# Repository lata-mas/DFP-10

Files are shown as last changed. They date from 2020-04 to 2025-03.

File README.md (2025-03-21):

# Dispositivo Factor de potencia

Este dispositivo se realizó gracias al apoyo del proyecto UNAM-PAPIIT IT103023.

El dispositivo FP-10 es un monitor de energía electrica desarrollado para medir parametros que permitan llevar un seguimiento del consumo energetico de un lugar, puesto que los datos obtenidos son enviados a una plataforma de internet para su visualizacion del tiempo de medición transcurrido. El dispositivo mide las siguientes variables: voltaje, corriente y factor de potencia. El monitor esta diseñado  para ser usado en una instalación trifásica y capaz de medir hasta 10 lineas.

A continuación se muestra el esquema general del dispositivo y una descripcción breve de los parametros que mide:

1. Corriente
2. Voltaje
3. Factor de potencia

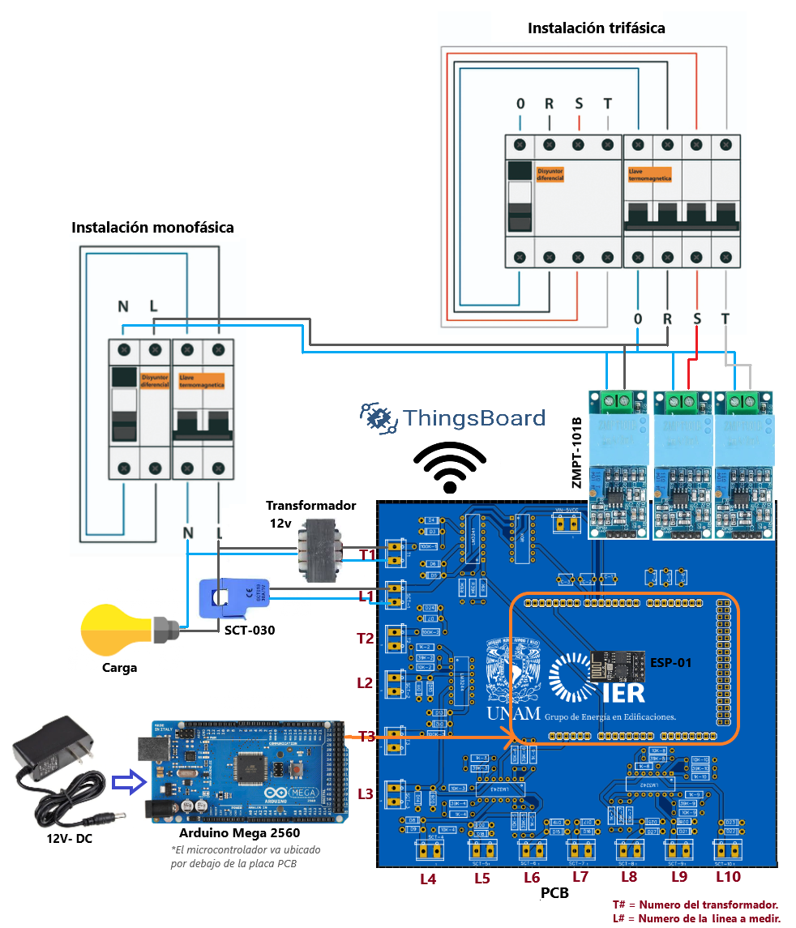
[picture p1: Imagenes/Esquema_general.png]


[Diagrama electrico](https://github.com/Dispositivos-Edificio-Bioclimatico/DFP-10/blob/master/Diagramas/circuito_acondicionamiento.png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)

**Corriente**

Sensor propuesto: SCT-013-030

El SCT-013-030 es un sensor de corriente no invasivo que permite medir la intensidad que atraviesa un conductor sin necesidad de cortar o modificar el conductor. La medición se realiza por inducción electromagnética y puede soportar hasta 30A.

**Voltaje**

Sensor propuesto: ZMPT101B

Es un módulo utilizado para medir la tensión de fase de corriente alterna. El sensor de voltaje AC está diseñado a partir de un transformador, por lo cual única y exclusivamente se puede utilizar para medir el voltaje de Corriente Alterna. El sensor incluye un circuito de amplificador operacional de precisión, señal para muestreo adecuado y función de compensación.
Puede medir hasta 250 V de AC de acuerdo con la salida analógica, la cual es ajustable.

**Factor de potencia**

Para medir el factor de potencia con un microcontrolador, se utilizan amplificadores operacionales para detectar el paso por cero de las señales de voltaje y corriente y para determinar el cambio de fase entre la fase de corriente y el voltaje. La medida del desfase se realiza únicamente para la fundamental entre corriente y tensión. Los amplificadores operacionales convierten señales de ondas sinusoidales con diferentes amplitudes provenientes de equipos de medición (pueden ser resistivos, divisores resistivos o transformadores de corriente y transformadores de tensión) en ondas rectangulares con una amplitud de aproximadamente 4 V, que luego se conectan a las entradas de la puerta XOR TTL. 

La salida de la puerta lógica XOR será 1 solo cuando las entradas tengan señales diferentes para cargas reactivas y la salida de la puerta lógica XOR será 0 cuando la carga sea resistiva. Entonces, cuando las fases de voltaje y corriente comienzan y terminan al mismo tiempo, la salida de la puerta lógica XOR será 0, y cuando la carga es inductiva o capacitiva, la salida de la puerta lógica XOR es 1, porque hay una diferencia de fase entre el voltaje y la corriente.

[Diagrama electrico](https://github.com/Dispositivos-Edificio-Bioclimatico/DFP-10/blob/master/Diagramas/Circuito%20factor%20de%20potencia.png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)

La lista de la electronica y materiales del dispositivo se encuentra en el archivo  [materiales](https://github.com/Dispositivos-Edificio-Bioclimatico/DFP-10/blob/master/Materiales/Lista_materiales_fp10.xlsx) o en [lista_drive](https://docs.google.com/spreadsheets/d/1BcxM7iUYsvm2OvhtAZ04L2_tH826wTiQOnGWFX_L0z4/edit)

## Elementos del repositorio
- [ ] Lista de costos
- [ ] src/ completos
- [ ] Pictograma de conexión
- [ ] Esquemático de conexión
- [ ] Archivos de diseño PCB
- [ ] Archivos gerber para el maquinado del PCB
- [x] Lista de materiales
- [ ] Planos CAD
- [ ] Archivos de diseño CAD
- [ ] Archivos STL para impresión 3D
- [ ] Manual de operación
- [ ] Manual de ensamble
- [ ] Fichas técnicas o datasheet de los módulos, sensores y componentes usados
- [ ] Documento de errores, soluciones y recomendaciones

### 1.1 Sobre los autores

|Nombre|Instituto/Organización|Email|
| --- | --- | --- |
|Juan Valle Bahena|ITZ|juanvb999@gmail.com|
|Guillermo Barrios del Valle|IER-UNAM|gbv@ier.unam.mx|
|Guillermo Ramírez Zúñiga|IER-UNAM|guraz@ier.unam.mx|
|Giovanni Velazquez Avilez ||velazquezgio96@gmail.com|

------------

# 2. Alcance

El dispositivo Factor de potencia tiene como alcance, en esta etapa, contar con toda la documentación necesaria  e incluso en atapa inicial de pruebas, después de ser trabajado por un grupo de personas se espera que el proyecto tenga todo lo que se necesita para que otras personas puedan entender el funcionamiento y requisitos de operación.

La audiencia a la que está destinada es:

- Por el momento a personal del IER-UNAM que se encuentra trabajando en el proyecto "Edificios demostrativos de diseño bioclimático en clima cálido subhúmedo en el Instituto de Energías Renovables UNAM".

Proyecto número 291600 del Fondo de Sustentabilidad Energética.
- Compañeros que se interesen en aportar al proyecto para mejorar o para replicarlo directamente.

------------

### Thingsboard

Dispositivo:
[**JUAN_VALLE_ENERGÍA**](http://iot.ier.unam.mx:8080/devices)

Dashboard:
[**JUAN_VALLE_ENERGÍA**](http://iot.ier.unam.mx:8080/dashboards/a7021b60-13df-11eb-9c3f-d1ead9980bc3)

**Las credenciales para acceder a Thinsgboard deberán ser solicitadas a los doctores**
------------

## PENDIENTES
1.- Comprar el sensor de corriente Hall Split core HSTS016L y hacer pruebas para verificar que el Factor de Potencia (FP) sea correcto.

2.- Poner una carcasa al dispositivo como proteccion para el sistema.

3.- Instalar el dispositivo en un edificio para probar la medición de las 10 lineas.

## RECOMENDACIONES
1.- Si se replica el sistema:

      * Montar el circuito en una placa de pruebas antes de montar en PCB para verificar que todos los componentes esten bien.
      
      * Será de ayuda usar un osciloscopio, para verificar que los circuitos integrados LM324N Y CD4030BE esten procesando la señal correctamente.
2.- Si el modulo ESP-01 (wifi) no logra inicializar se resuelve cambiando la velocidad de comunicación serial del modulo, en soft.begin (9600 o 115200).
      
3.- **IMPORTANTE** - **Extremar precauciones a la hora de hacer pruebas, ya que se trabaja con un voltaje que puede poner en riesgo la vida.**

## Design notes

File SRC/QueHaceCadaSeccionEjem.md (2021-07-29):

# Dispositivo Factor de potencia
Repositorio para el proyecto de medición del factor de potencia eléctrica para el nuevo edificio del IER-UNAM.

Esta versión del proyecto se conforma de un código modular para facilitar la manipulación de ciertos parámetros que nos ayuden a monitorear el consumo de energía eléctrica en los diferentes circuitos eléctricos del edificio nuevo del IER-UNAM.

A continuación se explican cada una de las funciones definidas en el archivo "funciones.py"

**Clase conteo**

Esta clase crea un objeto, este objeto será el sensor que se utilizará para la medición del flujo de agua.

La clase se compone de seis métodos. 

**Método init**

El método **init** no es más que para definir la varibale contador y la variable de entrada pin.

**Método callback**

El método **callback** es el que sirve para aumentar en 1 la variable contador cada señal recibida.

**Método irq**

El método **irq** es el que detecta cada pulso digital y envía la señal al metodo callback.

**Método ecuaciones**

Este método es el que aplica las constantes de conversión al conteo de pulsos digitales para así obtener una variable en Litros.

**Método datos**

Este método tan solo sirve para empaquetar los datos junto con una etiqueta para que estén listos.
para ser publicados en Thingsboard.	

**Método publica**

Este metodo se encarga de verificar si hay algún consumo de agua, de serlo así almacena los datos, en cuanto detecta que ya no lo hay, comineza un conteo, el conteo se interrumpe si vuelve a haber consumo, si el conteo concluye, publica los datos en Thingsboard.

**Última actualización de códigos por Miguel Ángel**

A continuación se explica de forma breve como se compone el código.

El código se modificó para hacer lecturas de ocho sensores. Cuenta con ocho secciones, una para cada número de sensores que se ocuparán. Todas las secciones se encuentran bloqueadas (comentadas). Esto con el fin de que se descomente la sección que se requiera, la primera sección es para un sensor, la segunda es para dos sensores y así sucesivamente hasta llegar a los ocho sensores.

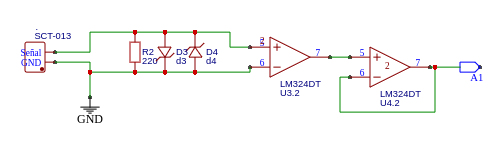
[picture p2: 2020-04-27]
Diagramas/circuito corriente.png

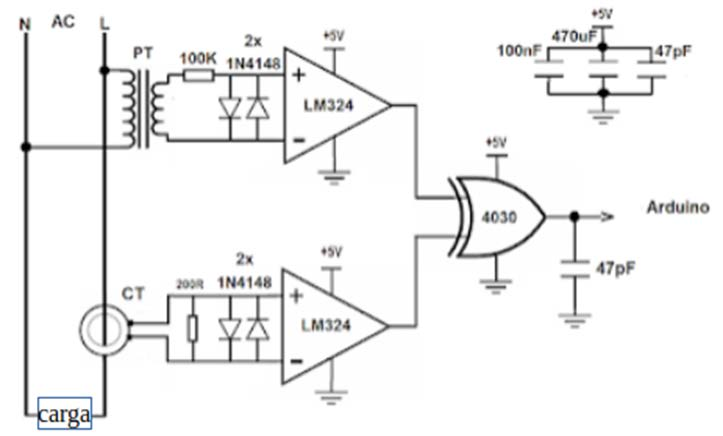
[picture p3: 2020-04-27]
Diagramas/Circuito factor de potencia.png

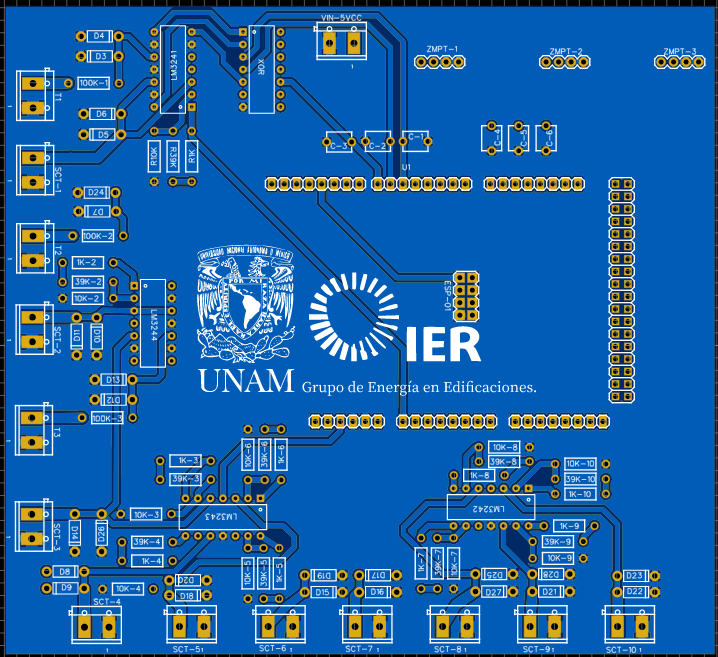
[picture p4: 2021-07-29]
Diagramas/pcb_10_fases_easyeda.png

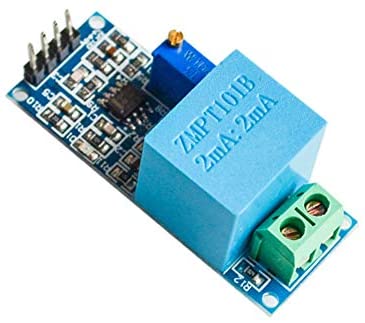
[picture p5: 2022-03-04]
Imagenes/zmpt101b.jpg

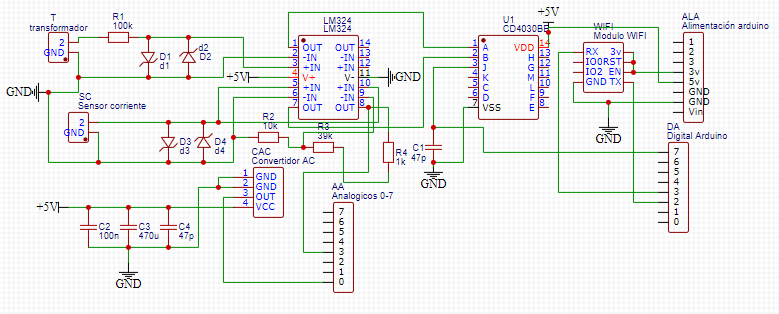
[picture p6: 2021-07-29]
Diagramas/circuito_acondicionamiento.png

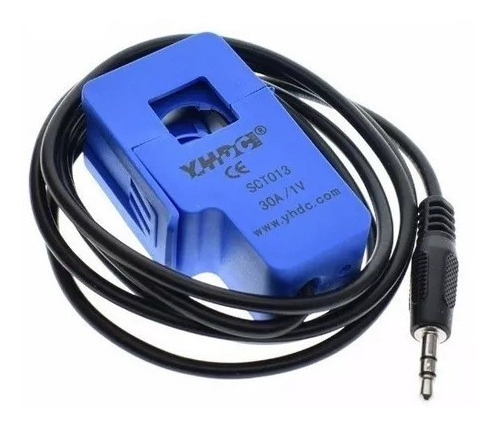
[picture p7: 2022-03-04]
Imagenes/sct_013_030.jpg

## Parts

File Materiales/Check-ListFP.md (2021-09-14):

- [x] Lista de costos
- [x] SRC completos
- [x] Pictograma de conexión
- [x] Esquemático de conexión
- [x] Archivos de diseño PCB
- [x] Archivos gerber para el maquinado del PCB
- [x] Lista de materiales
- [x] Planos CAD
- [x] Archivos de diseño CAD
- [x] Archivos STL para impresión 3D
- [ ] Manual de operación
- [ ] Manual de ensamble
- [x] Fichas técnicas o datasheet de los módulos, sensores y componentes usados
- [ ] Documento de errores, soluciones y recomendaciones

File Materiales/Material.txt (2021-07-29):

Lista de material para armar un pcb completo:
10 sensores sct013 de 30A-1v
3 sensores zmpt101b
3 transformadores de 110v a 12v
1 compuerta logica xor (con su base o zocalo)
4 CI Lm324 (con sus bases zif o zocalos en caso de ser necesarios)
14 bloques de 2 terminales (borneras verdes)
2 tiras de pines macho para ensamblar el arduino mega al pcb.
3 resistencias 100k
10 resistencias de 1k
10 resistencias de 39k
10 resistencias de 10k
26 diodos zener de 5v
capacitores : 4 de 47pf, 1 de 100 nf, 1 de 470uf
1 arduino mega.
1 modulo esp01 (wifi)

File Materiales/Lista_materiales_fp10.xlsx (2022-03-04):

Lista de Materiales
Cantidad | Componente | Link de compra
10 | SCT-030 | https://www.agelectronica.com/detalle.php?p=OKY3318-2
3 | ZMPT101B | https://articulo.mercadolibre.com.mx/MLM-696910645-sensor-de-voltaje-ac-zmpt101b-transformador-de-tension-_JM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
3 | Transformador 12V | https://www.agelectronica.com/detalle.php?p=TRANS-12/1200
4 | LM324 | https://www.agelectronica.com/detalle.php?p=LM%20324N
1 | XOR (CD4030BE) | https://www.agelectronica.com/detalle.php?p=CD%204030BE
26 | Diodo Zener | https://www.agelectronica.com/detalle.php?p=1N%204728A
3 | R100K | https://www.agelectronica.com/detalle.php?p=RC-100K/1/2
10 | R1K | https://www.agelectronica.com/detalle.php?p=RC-1K/1/2
10 | R39K | https://www.agelectronica.com/detalle.php?p=RC-39K/1/2
10 | R10K | https://www.agelectronica.com/detalle.php?p=RC-10K/1/2
4 | C47pF | https://www.agelectronica.com/detalle.php?p=CC-47/1000V-WELSON
3 | C470uF | https://www.agelectronica.com/detalle.php?p=CE-470/35V-TEAPO
3 | 100 nF | https://www.agelectronica.com/detalle.php?p=104M06QC150*
1 | ESP-01 | https://www.agelectronica.com/detalle.php?p=ESP-01S
1 | Arduino Mega 2560 | https://www.agelectronica.com/detalle.php?p=A000067
1 | Eliminador 12v | https://www.agelectronica.com/detalle.php?p=GFP181U-1210/JH
14 | Bornera 2 pines | https://www.agelectronica.com/detalle.php?p=GFP181U-1210/JH

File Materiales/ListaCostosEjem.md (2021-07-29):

# Lista de costos del Dispositivo Factor de Potencia Eléctrica
#### Título del diseño:|Dispositivo Factor de Potencia Eléctrica|
#### Fecha de diseño:|Martes 28/Julio/2021 | 
#### Última modificación del diseño:|Martes 28/Julio/2021|
|  Cantidad | Referencias | Número de parte | Código almacén | Coste Unitario  |
| --- | --- | --- | --- | --- |
|2 Integrados| U1-U2  |LM324 | |$12.00 |
|Subtotal| | | | *$24.00* |
|8 Resistencias| R1-R8 | 1KΩ | W1K | $1.50 |
| *Subtotal*  | | | |*$12.0*|
|*8 TBLOCK-M3*|J1-J8|| | $4.65  |
|*1 USBCONN*|J9| | |$15.73|
|*1 NodeMCU3*|NMCU2| | |$94.00|
|*8 YF-S201*|S1-S8| | |$130.00|
|*Subtotal*|| | |*$1186.93*|
|**Total**|| | |**$1222.93**|

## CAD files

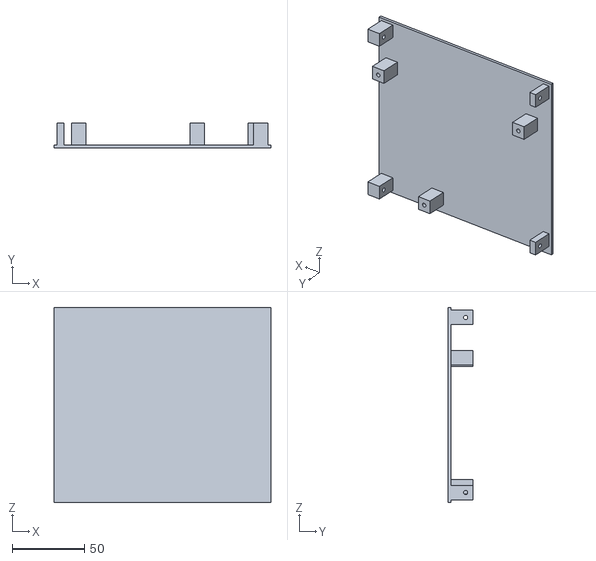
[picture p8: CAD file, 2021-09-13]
CAD/TapaSTL.STL
150.0 x 17.0 x 135.0

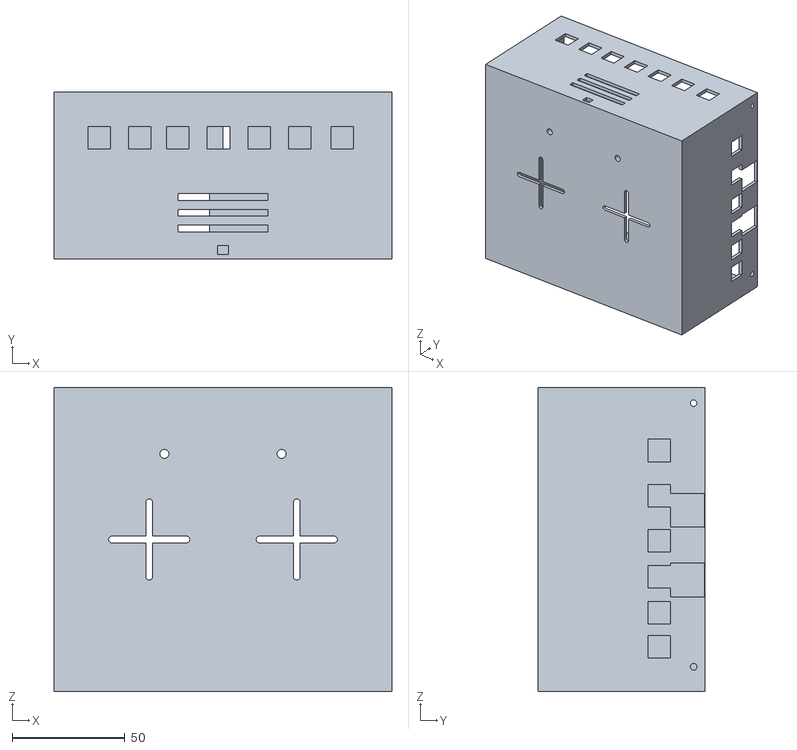
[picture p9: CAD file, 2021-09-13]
CAD/BaseSTL.STL
150.0 x 74.0 x 135.0

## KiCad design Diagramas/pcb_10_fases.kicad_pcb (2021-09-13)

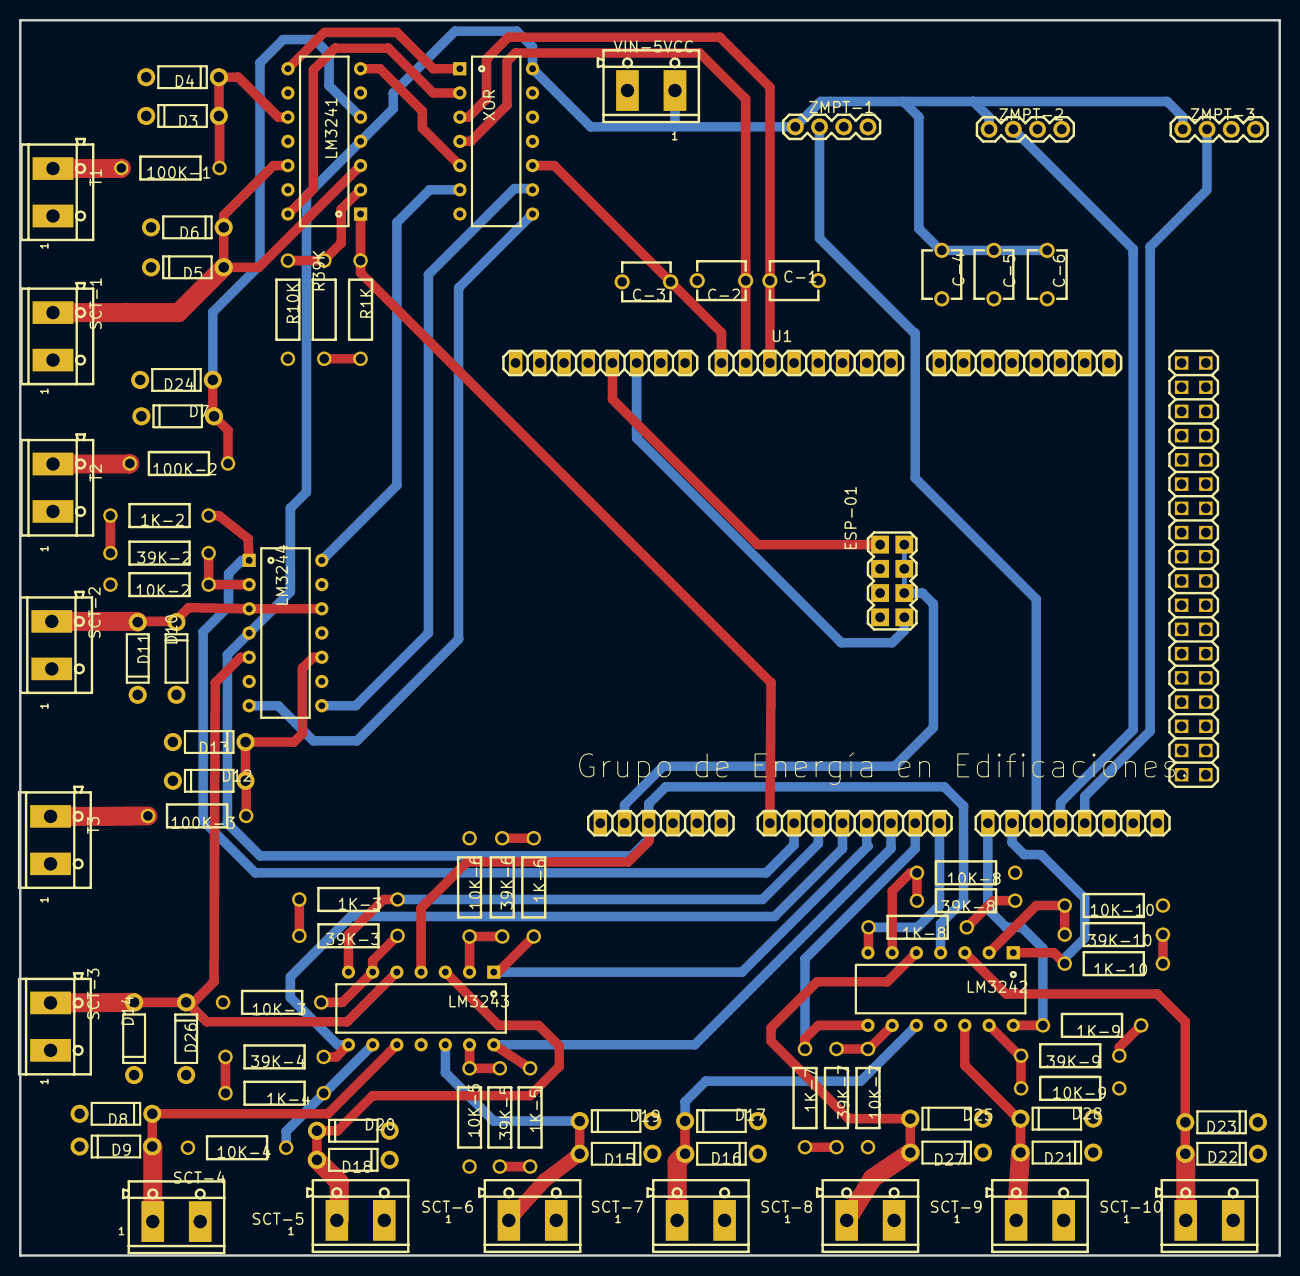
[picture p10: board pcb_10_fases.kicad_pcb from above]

Board: 2 copper layers, 132.1 x 129.5 mm, 89 parts (0 on the bottom side), 56 nets.

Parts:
1K-2, 1K-3, 1K-4, 1K-5, 1K-6, 1K-7, 1K-8, 1K-9, 1K-10, 10K-2, 10K-3, 10K-4, 10K-5, 10K-6, 10K-7, 10K-8, 10K-9, 10K-10, 39K-2, 39K-3, 39K-4, 39K-5, 39K-6, 39K-7, 39K-8, 39K-9, 39K-10, 100K-1, 100K-2, 100K-3: RES-TH_BD2.4-L6.3-P10.30-D0.6
C-1, C-2, C-3, C-4, C-5, C-6: CAP-TH_L5.0-W4.0-P5.00-D1.0
D3, D4, D5, D6, D7, D8, D9, D10, D11, D12, D13, D14, D15, D16, D17, D18, D19, D20, D21, D22, D23, D24, D25, D26, D27, D28: DO-35
ESP-01: 2X4
LM3241, LM3242, LM3243, LM3244: DIP14
R1K, R10K, R39K: RES-TH_BD2.4-L6.3-P10.30-D0.6
SCT-1, SCT-2, SCT-3, SCT-4, SCT-5, SCT-6, SCT-7, SCT-8, SCT-9, SCT-10: 1; TERMINAL_BLOCK_2P_5
T1, T2, T3: 1; TERMINAL_BLOCK_2P_5
U1: MEGA_ARDUINO_2
VIN-5VCC: 1; TERMINAL_BLOCK_2P_5
XOR: DIP14
ZMPT-1, ZMPT-2, ZMPT-3: 1X04-BIG

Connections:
GND: 10K-2.1, 10K-3.1, 10K-4.1, 10K-5.1, 10K-6.2, 10K-7.1, 10K-8.2, 10K-9.2, 10K-10.2, C-1.2, C-2.1, C-3.1, C-4.1, C-5.1, C-6.1, D3.2, D4.1, D5.2, D6.1, D7.2, D10.2, D11.1, D12.2, D13.1, D14.2, D15.2, D16.2, D17.1, D18.2, D19.1, D20.1, D21.2, D22.2, D23.2, D24.1, D25.1, D26.1, D27.2, D28.1, ESP-01.7, LM3241.6, LM3241.9, LM3241.11, LM3241.13, LM3242.11, LM3243.11, LM3244.6, LM3244.9, LM3244.11, LM3244.13, R10K.1, SCT-1.1, SCT-2.1, SCT-3.1, SCT-4.1, SCT-5.1, SCT-6.1, SCT-7.1, SCT-8.1, SCT-9.1, SCT-10.1, T1.1, T2.1, T3.1, U1.4, U1.5, VIN-5VCC.2, XOR.7, ZMPT-1.3, ZMPT-1.4, ZMPT-2.3, ZMPT-2.4, ZMPT-3.3, ZMPT-3.4
S$2705: 100K-1.1, T1.2
S$2707: 100K-1.2, D3.1, D4.2, LM3241.10
S$2727: D5.1, D6.2, LM3241.3, LM3241.12, SCT-1.2
S$2733: LM3241.14, XOR.2
S$3126: LM3241.2, R10K.2, R39K.1
S$3129: R1K.1, R39K.2
S$3199: 100K-2.1, T2.2
S$3249: U1.36, XOR.3
S$3313: 100K-2.2, D7.1, D24.2, LM3241.5
S$3334: LM3241.7, XOR.5
S$3339: D10.1, LM3244.3, LM3244.12, SCT-2.2
S$3345: 10K-2.2, 39K-2.2, LM3244.2
S$3348: 1K-2.1, 39K-2.1
S$3350: 1K-2.2, LM3244.1, U1.8
S$3353: LM3244.14, XOR.6
S$3375: LM3244.8, XOR.9
S$3405: D14.1, D26.2, LM3243.5, LM3244.5, SCT-3.2
S$4354: U1.37, XOR.4
S$4365: 1K-3.2, LM3243.7, U1.9
S$4400: 1K-3.1, 39K-3.1
S$4411: U1.38, XOR.10
S$4418: D8.2, D9.1, LM3243.10, SCT-4.2
S$4433: LM3243.8, U1.10
S$4450: D18.1, D20.2, LM3243.3, SCT-5.2
S$4457: 10K-5.2, 39K-5.2, LM3243.13
S$4460: 1K-5.1, 39K-5.1
S$4462: 1K-5.2, LM3243.14, U1.12
S$4466: D15.1, SCT-6.2
S$4529: D19.2, LM3243.12
S$4531: 10K-6.1, 39K-6.1, LM3243.2
S$4534: 1K-6.2, 39K-6.2
S$4536: 1K-6.1, LM3243.1, U1.11
S$4552: D16.1, D17.2, LM3242.10, SCT-7.2
S$4559: 10K-7.2, 39K-7.2, LM3242.9
S$4562: 1K-7.1, 39K-7.1
S$4564: 1K-7.2, LM3242.8, U1.13
S$4663: D25.2, D27.1, LM3242.5, SCT-8.2
S$4669: 10K-8.1, 39K-8.1, LM3242.6
S$4672: 1K-8.2, 39K-8.2
S$4674: 1K-8.1, LM3242.7, U1.14
S$4679: D21.1, D28.2, LM3242.12, SCT-9.2
S$4742: 10K-9.1, LM3242.13
S$4745: 1K-9.2, 39K-9.2
S$4747: 1K-9.1, LM3242.14, U1.15
S$4750: D22.1, D23.1, LM3242.3, SCT-10.2
S$4755: 10K-10.1, 39K-10.1, LM3242.2
S$4758: 1K-10.2, 39K-10.2
S$4760: 1K-10.1, LM3242.1, U1.16
S$4992: ESP-01.2, ESP-01.4, ESP-01.6, U1.2
S$4998: ESP-01.8, U1.41
S$5000: ESP-01.1, U1.42
S$5174: U1.17, ZMPT-1.2
S$5176: U1.18, ZMPT-2.2
S$5178: U1.19, ZMPT-3.2
S$6595: C-4.2, C-5.2, C-6.2, LM3241.4, LM3242.4, LM3243.4, LM3244.4, U1.3, VIN-5VCC.1, XOR.14, ZMPT-1.1, ZMPT-2.1, ZMPT-3.1

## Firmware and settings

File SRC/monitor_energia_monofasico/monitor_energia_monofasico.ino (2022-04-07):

#include <WiFiNINA.h>

#include "PZEM004Tv30.h"
#include <SoftwareSerial.h>

#if defined(ESP32)
    #error "Software Serial is not supported on the ESP32"
#endif

/* Use software serial for the PZEM
 * Pin 12 Rx (Connects to the Tx pin on the PZEM)
 * Pin 13 Tx (Connects to the Rx pin on the PZEM)
*/
#if !defined(PZEM_RX_PIN) && !defined(PZEM_TX_PIN)
#define PZEM_RX_PIN 12
#define PZEM_TX_PIN 13
#endif

unsigned long previousMillis = 0;
unsigned long intervalSensors = 10000;

int e = 0;

#include <ArduinoHttpClient.h>


#include "arduino_secrets.h"
///////please enter your sensitive data in the Secret tab/arduino_secrets.h
char ssid[] = SECRET_SSID;        // your network SSID (name)
char pass[] = SECRET_PASS;    // your network password (use for WPA, or use as key for WEP)

WiFiClient wifiClient;
HttpClient httpClient = HttpClient(wifiClient, SECRET_SERVER, SECRET_PORT);

SoftwareSerial pzemSWSerial(PZEM_RX_PIN, PZEM_TX_PIN);
PZEM004Tv30 pzem(pzemSWSerial);

void setup() {
    /* Debugging serial */
    Serial.begin(9600);

  Serial.print("Attempting to connect to WPA SSID: ");
  Serial.println(ssid);
  while (WiFi.begin(ssid, pass) != WL_CONNECTED) {
    // failed, retry
    Serial.print(".");
    delay(1000);
  }

  Serial.println("You're connected to the network");
}

void loop() {

    unsigned long currentMillis = millis();

    if (currentMillis - previousMillis >= intervalSensors) {
      previousMillis = currentMillis;

    Serial.print("Custom Address:");
    Serial.println(pzem.readAddress(), HEX);

    // Read the data from the sensor
    float voltage = pzem.voltage();
    float current = pzem.current();
    float power = pzem.power();
    float energy = pzem.energy();
    float frequency = pzem.frequency();
    float pf = pzem.pf();

    // Check if the data is valid
    if(isnan(voltage)){
        Serial.println("Error reading voltage");
    } else if (isnan(current)) {
        Serial.println("Error reading current");
    } else if (isnan(power)) {
        Serial.println("Error reading power");
    } else if (isnan(energy)) {
        Serial.println("Error reading energy");
    } else if (isnan(frequency)) {
        Serial.println("Error reading frequency");
    } else if (isnan(pf)) {
        Serial.println("Error reading power factor");
    } else {

        // Print the values to the Serial console
        Serial.print("Voltage: ");      Serial.print(voltage);      Serial.println("V");
        Serial.print("Current: ");      Serial.print(current);      Serial.println("A");
        Serial.print("Power: ");        Serial.print(power);        Serial.println("W");
        Serial.print("Energy: ");       Serial.print(energy,3);     Serial.println("kWh");
        Serial.print("Frequency: ");    Serial.print(frequency, 1); Serial.println("Hz");
        Serial.print("PF: ");           Serial.println(pf);

    Serial.println(" ");
    
    sendvolt();
    sendcurrent();
    sendpower();
    sendfp();
    } 

    Serial.println();
    }
}

void sendfp(){

    float pf = pzem.pf();

  if (pf>0) {
    
  
   String payload = "{";
    payload += "fp: ";
    payload += pf;
    payload += "}";

    Serial.println("POST... " + payload);

  
    httpClient.post(SECRET_TOPIC, "application/json", payload);

    int statusCode = httpClient.responseStatusCode();  
    String response = httpClient.responseBody();
    Serial.print("Status code: ");
    Serial.print(statusCode);
    Serial.print(" ");
    Serial.println(response);
    Serial.print(" ");

   }
   else {
    printf("no hay datos validos");
   }
}

void sendvolt(){

    float voltage = pzem.voltage();

     if (voltage>0) {

  
   String payload = "{";
    payload += "voltaje: ";
    payload += voltage;
    payload += "}";

    Serial.println("POST... " + payload);

  
    httpClient.post(SECRET_TOPIC, "application/json", payload);

    int statusCode = httpClient.responseStatusCode();  
    String response = httpClient.responseBody();
    Serial.print("Status code: ");
    Serial.print(statusCode);
    Serial.print(" ");
    Serial.println(response);
    Serial.print(" ");

    }
   else {
    printf("no hay datos validos");
   }
     
}

void sendcurrent(){

    float current = pzem.current();

  if (current>0) {
    
   String payload = "{";
    payload += "corriente: ";
    payload += current;
    payload += "}";

    Serial.println("POST... " + payload);

  
    httpClient.post(SECRET_TOPIC, "application/json", payload);

    int statusCode = httpClient.responseStatusCode();  
    String response = httpClient.responseBody();
    Serial.print("Status code: ");
    Serial.print(statusCode);
    Serial.print(" ");
    Serial.println(response);
    Serial.print(" ");

    }
   else {
    printf("no hay datos validos");
   }
     
}

void sendpower(){

    float power = pzem.power();

  if (power>0) {
  
   String payload = "{";
    payload += "potencia: ";
    payload += power;
    payload += "}";

    Serial.println("POST... " + payload);

  
    httpClient.post(SECRET_TOPIC, "application/json", payload);

    int statusCode = httpClient.responseStatusCode();  
    String response = httpClient.responseBody();
    Serial.print("Status code: ");
    Serial.print(statusCode);
    Serial.print(" ");
    Serial.println(response);
    Serial.print(" ");

    }
   else {
    printf("no hay datos validos");
   }
     
}

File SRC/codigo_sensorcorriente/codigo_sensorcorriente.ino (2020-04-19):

//----Librerias-------------------//
//#include <WiFiEspClient.h>
#include <WiFiEsp.h>
//#include <WiFiEspUdp.h>
#include "SoftwareSerial.h"
#include <ThingsBoard.h> 
#include <Wire.h>
#include "factores.h"
//-------------------------------//

//-----datos de la red-------//
//#define WIFI_AP "IER"
//#define WIFI_PASSWORD "acadier2014"
#define WIFI_AP "INFINITUMjpdm"
#define WIFI_PASSWORD "5cbbb04d21"

#define TOKEN "asm8CrU6nQfGsW3Xl7Fn"  //--------Dispositivo tb-------//  
char thingsboardServer[] = "iot.ier.unam.mx"; //------Servidor ThingsBoard--------//

// Initialize the Ethernet client object
WiFiEspClient espClient;                                     
ThingsBoard tb(espClient);                                    

SoftwareSerial soft(2, 3); // RX, TX                          
int status = WL_IDLE_STATUS;
unsigned long lastSend = 0;


int pinpf = 7;
int pinvolts = 1;
int pincorriente = 3;

factores fact;

//------------------------------------------------------------//
void setup() { 
  // initialize serial for debugging
  Serial.begin(9600);
  InitWiFi();                                                
  fact.defvar(pinvolts, pinpf, pincorriente);
}
//------------------------------------------------------------//

//-------------------------------------------------------------//
void loop() {
  conectar();
  if ( millis() - lastSend > 1000 ) { // Update and send only after 1 seconds

 fact.calcular();   
    
   tb.sendTelemetryFloat("voltaje", fact.volts);
    tb.sendTelemetryFloat("corriente", fact.Irms);
    tb.sendTelemetryFloat("factor_p", fact.pf);
    
    lastSend = millis();
  }
  tb.loop();
}
//..........................................................//


//-------------------------------------------------------------------------------------------------------------//
void InitWiFi()
{
  // initialize serial for ESP module
  soft.begin(9600);
  // initialize ESP module
  WiFi.init(&soft);
  // check for the presence of the shield
  if (WiFi.status() == WL_NO_SHIELD) {
    Serial.println("WiFi shield not present");
    // don't continue
    while (true);
  }
  Serial.println("Connecting to AP ...");
  // attempt to connect to WiFi network
  while ( status != WL_CONNECTED) {
    Serial.print("Attempting to connect to WPA SSID: ");
    Serial.println(WIFI_AP);
    // Connect to WPA/WPA2 network
    status = WiFi.begin(WIFI_AP, WIFI_PASSWORD);
    delay(500);
  }
  Serial.println("Connected to AP");
}
//---------------------------------------------------------------------------------------------------------------//

//---------------------------------------------------------------------------------------------------------------//
void reconnect() {
  // Loop until we're reconnected
  while (!tb.connected()) {
    Serial.print("Connecting to ThingsBoard node ...");
    // Attempt to connect (clientId, username, password)
    if ( tb.connect(thingsboardServer, TOKEN) ) {
      Serial.println( "[DONE]" );
    } else {
      Serial.print( "[FAILED]" );
      Serial.println( " : retrying in 5 seconds" );
      // Wait 5 seconds before retrying
      delay( 5000 );
    }
  }
}

 void conectar() {
  status = WiFi.status();
  if ( status != WL_CONNECTED) {
    while ( status != WL_CONNECTED) {
      Serial.print("Attempting to connect to WPA SSID: ");
      Serial.println(WIFI_AP);
      // Connect to WPA/WPA2 network
      status = WiFi.begin(WIFI_AP, WIFI_PASSWORD);
      delay(500);
    }
    Serial.println("Connected to AP");
  }
  if ( !tb.connected() ) {
    reconnect();
  }
  }
//-------------------------------------------------------------------------------------------------------------------//

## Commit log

2020-02-14 código inicial de factor de potencia
2020-04-13 Se cambio el código para la obtención del voltaje, se cambio tambien la libreria, Libreri añadida Emonlib.h
2021-09-13 Actualicé
    [BaseSTL.STL, TapaSTL.STL]
2022-03-04 agregue lista de materiales
    [Lista_materiales_fp10.xlsx]
2022-04-07 agregué codigo para circuito monofasico
